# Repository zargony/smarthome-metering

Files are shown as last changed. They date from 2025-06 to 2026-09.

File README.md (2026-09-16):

# Smart Home Energy Metering

A device for capturing energy consumption at home by reading energy meters.

This device, built around an ESP32-C3, collects data from electricity, gas, and water meters and provides it to smart home systems like [Home Assistant] for automation and long-term analysis. Housed in a DIN rail enclosure, it fits seamlessly into a standard European meter cabinet.

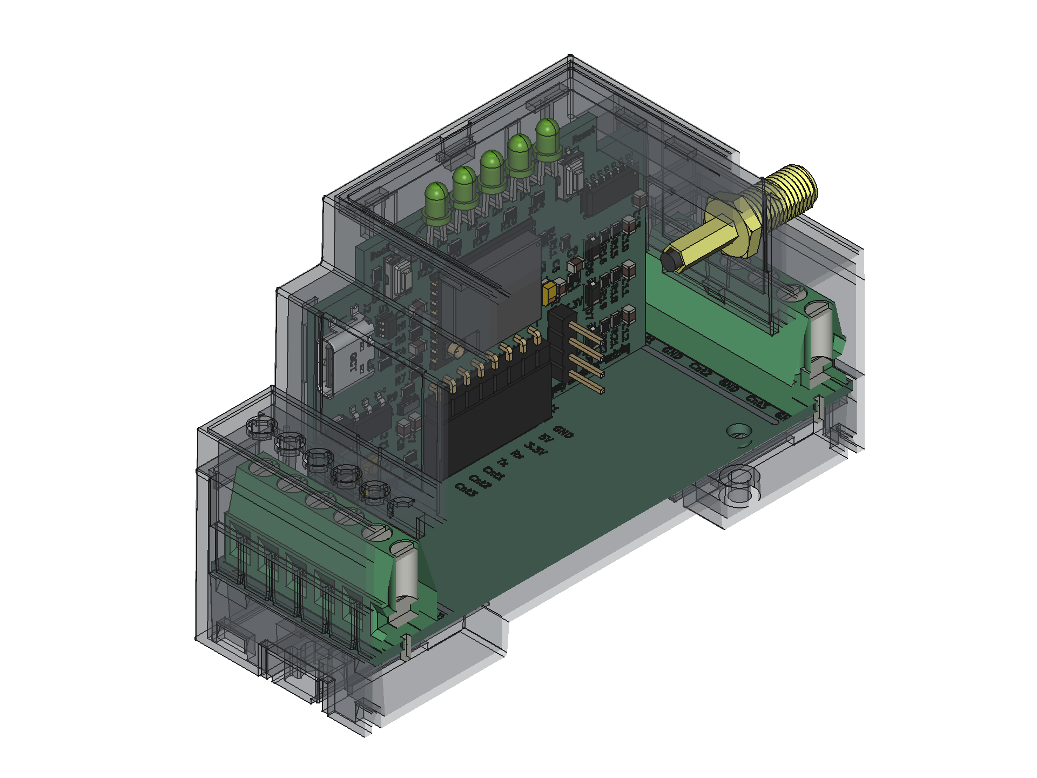
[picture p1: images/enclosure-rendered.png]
Rendering of PCB in enclosure
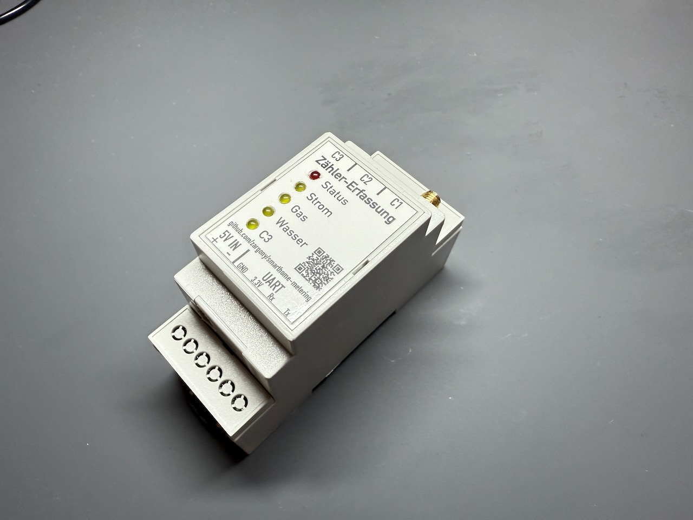
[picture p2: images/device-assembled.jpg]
Fully assembled device
 

## Hardware

The standard [DIN rail enclosure] can be mounted onto a DIN rail and shows status and activity LEDs when installed in a meter cabinet. [Power supply] and sensor connections are exposed via screw terminals. An external antenna can be connected to the SMA socket and is best mounted outside the cabinet for good Wifi connection. A USB-C socket exposes the ESP32-C3 Serial/JTAG port for easy programming/debugging (e.g. if OTA failed).

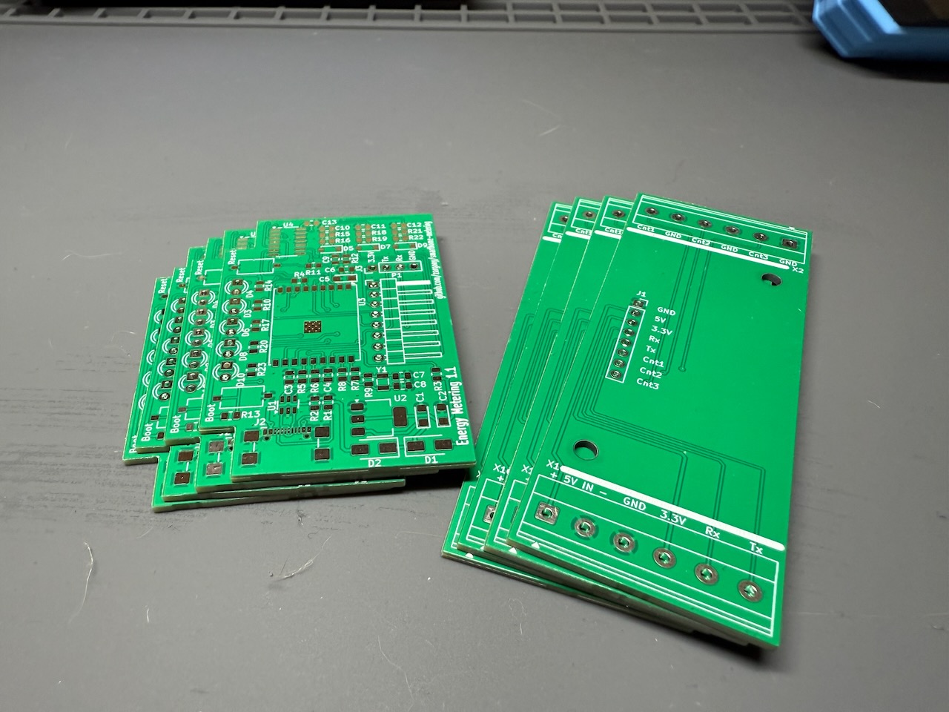
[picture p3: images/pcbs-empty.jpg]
Empty PCBs
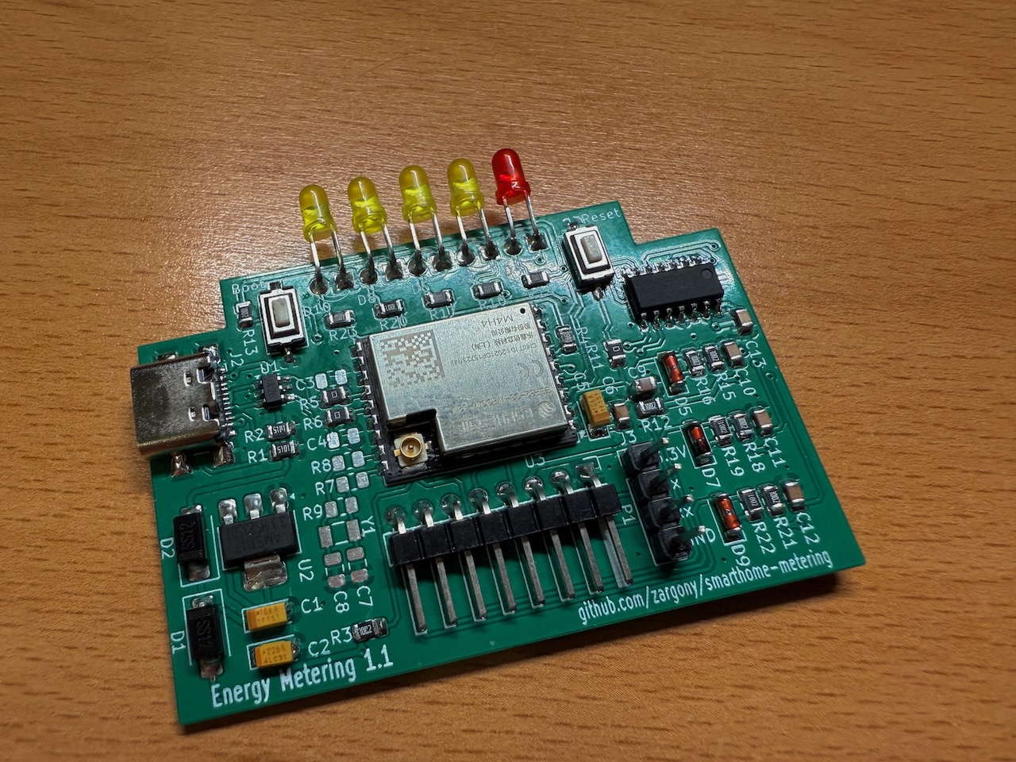
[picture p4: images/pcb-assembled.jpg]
Assembled main PCB
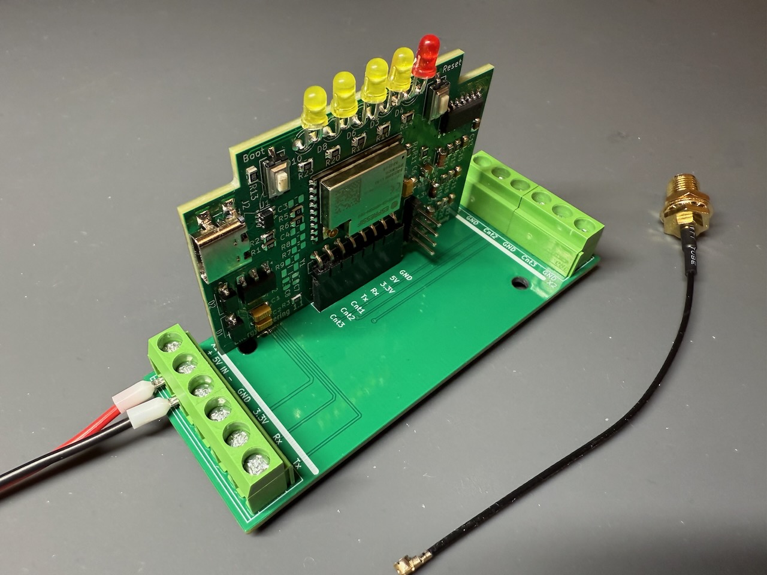
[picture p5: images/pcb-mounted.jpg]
Main PCB mounted onto base PCB
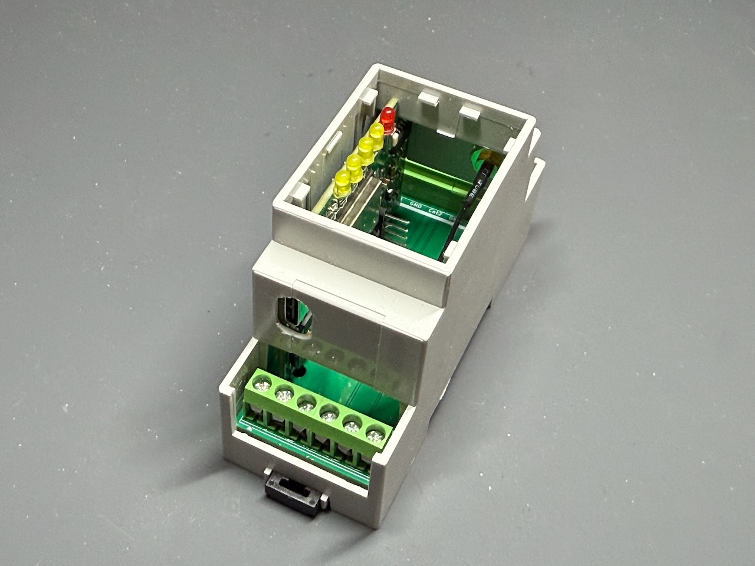
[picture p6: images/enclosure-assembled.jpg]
Enclosure and PCB assembled
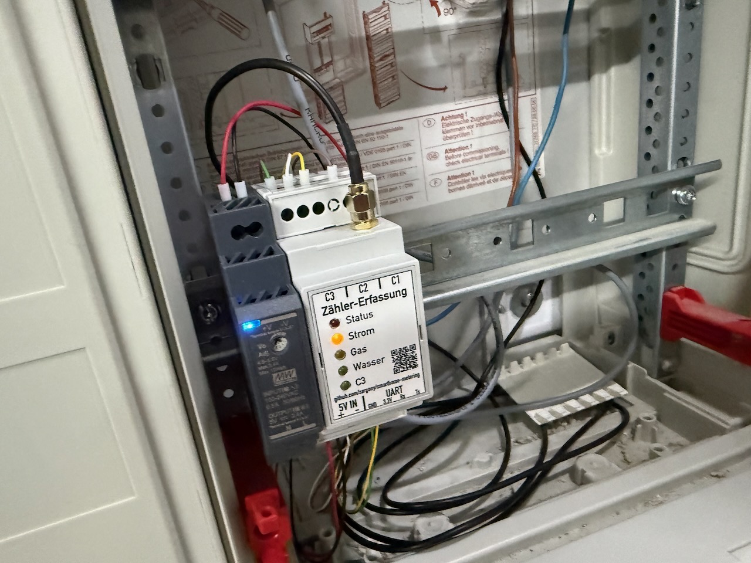
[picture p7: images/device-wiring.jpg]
Wiring of device in meter cabinet
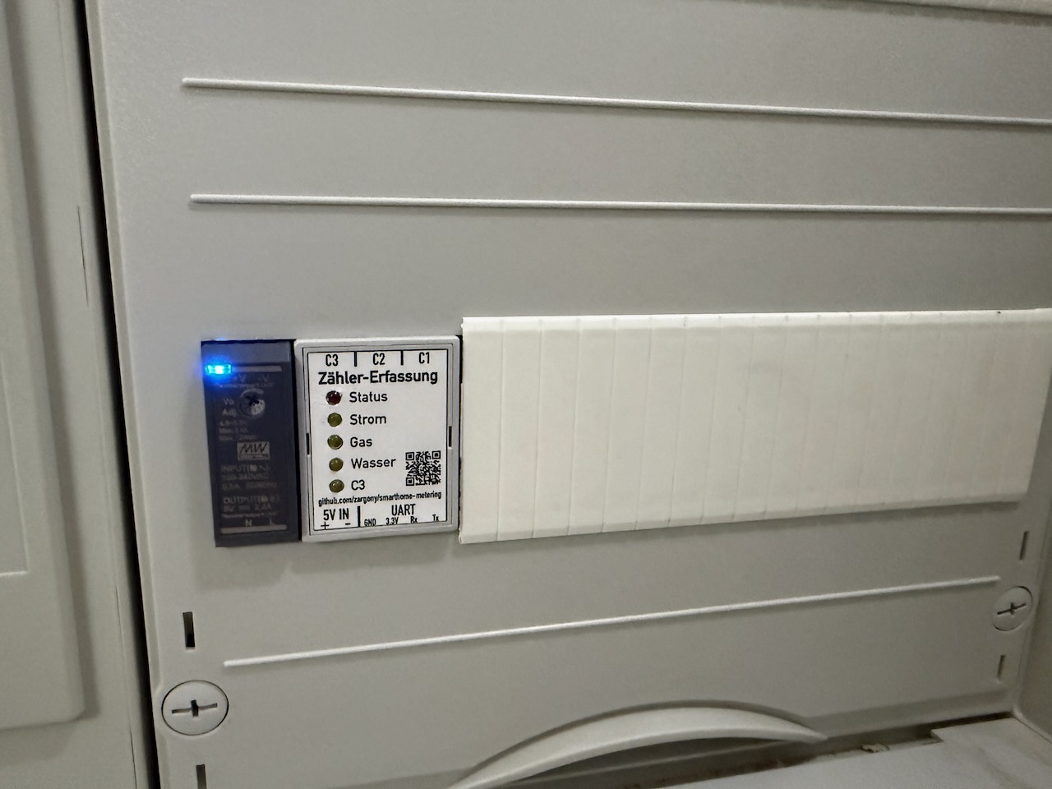
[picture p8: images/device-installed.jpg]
Device installed in meter cabinet
     

### Sensor connections

This device provides a 3.3V bidirectional UART for reading a serial data stream, e.g. an electric meter's infrared interface. Additionally 3 debounced impulse contacts can be used to capture simple count impulses, e.g. from reed contacts on water and gas meters (or electric meters without IR interface but impulse LEDs).

| GPIO  | Direction | Usage |
|---|---|---|
| GPIO3 | Input, Pull-Up, Debounced | Contact 1 (gas meter) |
| GPIO4 | Input, Pull-Up, Debounced | Contact 2 (water meter) |
| GPIO5 | Input, Pull-Up, Debounced | Contact 3 |
| GPIO6 | Input | UART Rx (electrical meter) |
| GPIO7 | Output | UART Tx |
| GPIO8 | Output | Status LED (active low) |
| GPIO9 | Input, Pull-Up | Boot button |

## Firmware

There's a variety of ESP32 firmwares available that can be used. Most popular are [ESPHome] and [Tasmota]. With proper configuration, it captures energy meters readings and can submit readings to [Home Assistant] or an MQTT broker where they can be picked up by various tools like [Node-RED] or [Telegraf].

See [`metering.yaml`](esphome/metering.yaml) for an example ESPHome configuration of this device which is auto-discovered with all metrics in Home Assistant.

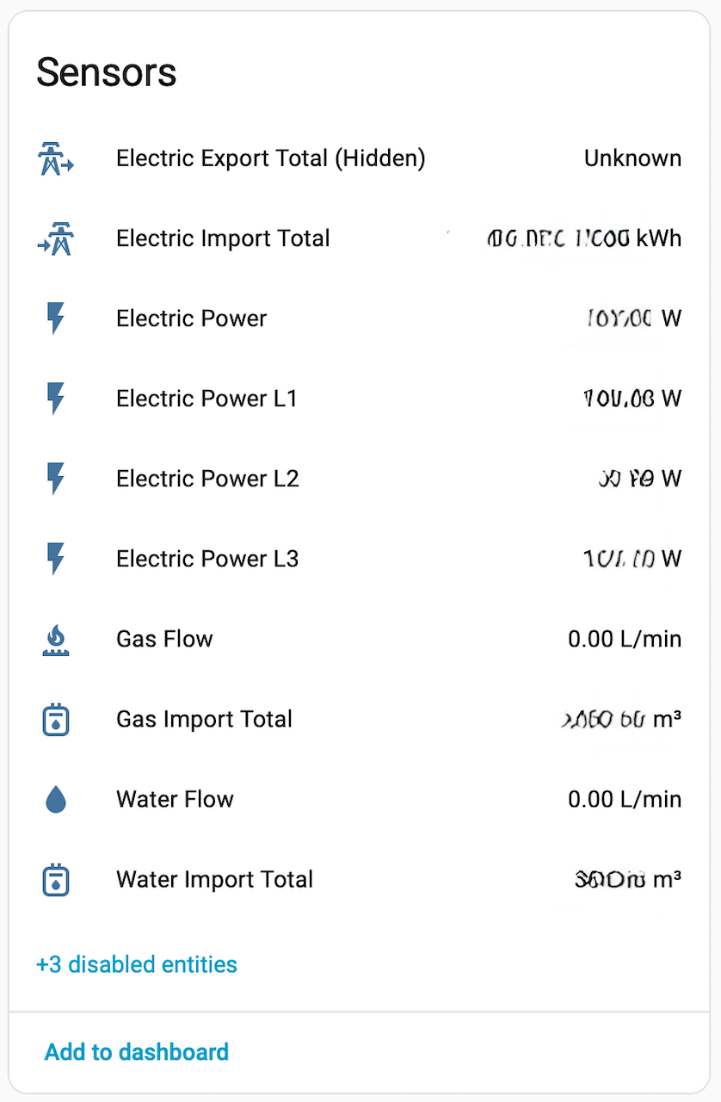
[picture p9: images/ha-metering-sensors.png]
Home Assistant showing energy metering sensors
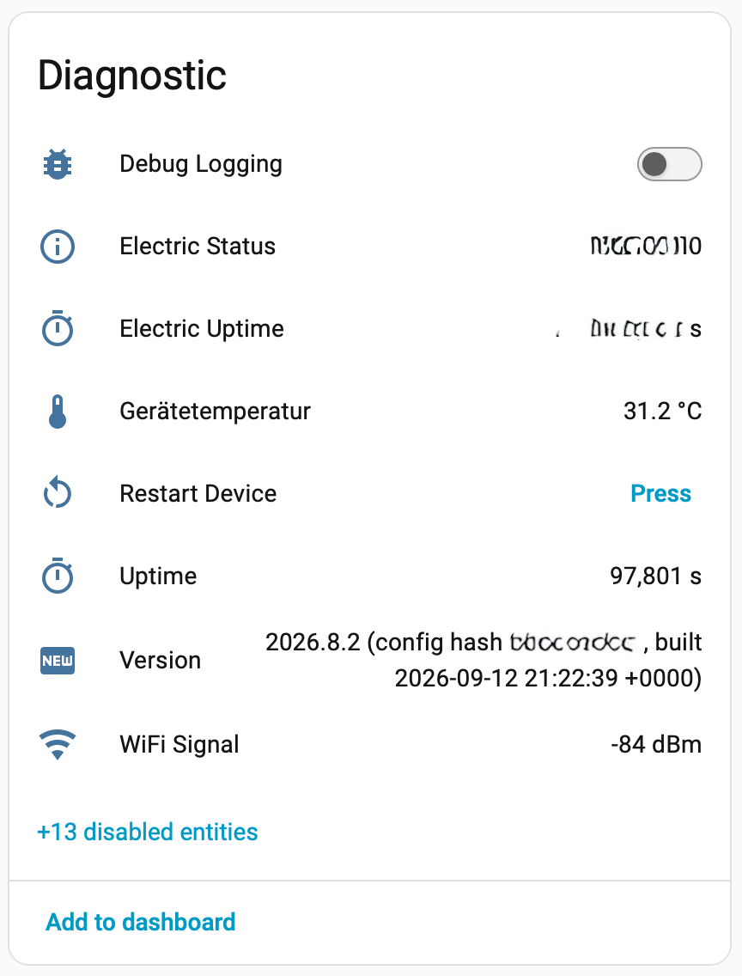
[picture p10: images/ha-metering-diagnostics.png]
Home Assistant showing device diagnostics
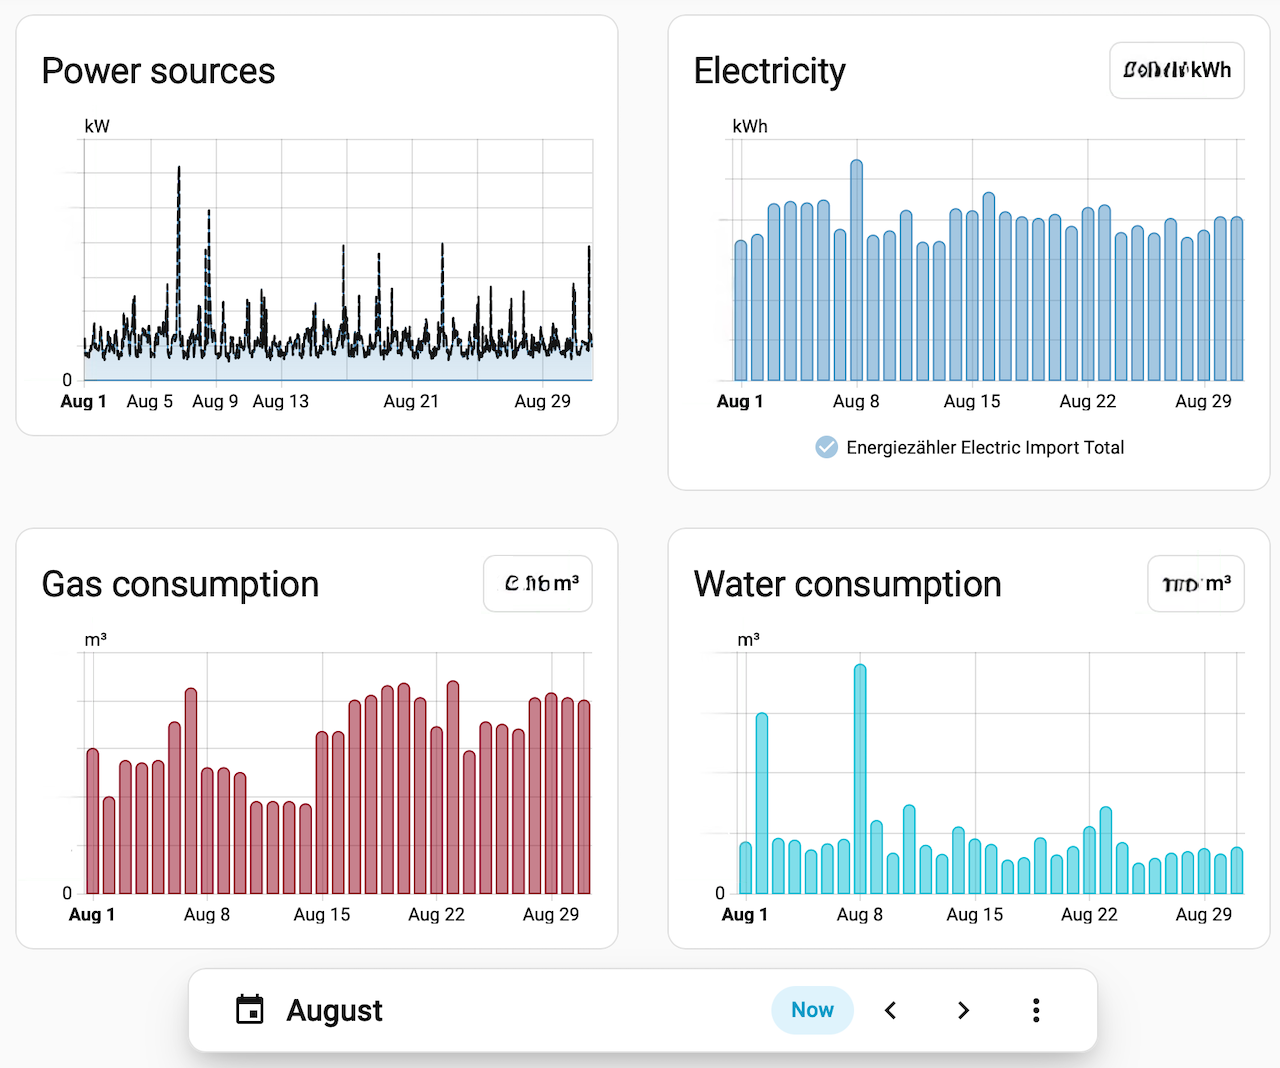
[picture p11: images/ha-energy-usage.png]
Home Assistant showing energy usage graphs
  

## My Setup (Example)

I use this device with sensors described below. It's tailored to my specific environment and some links reference German websites, as they relate to the energy meters installed in my home. However, you may still find parts of it useful for your own setup.

### Electrical

The [eBZ DD3] electrical meter has an infrared UART interface that continuously provides information about voltage, current, power and total consumption. Several [DIY IR sensors] (and [schematics][DIY IR sensor schmatic]) are available online, e.g. I got a Hichi IR (the simple TTL variant, no Wifi or USB). It works fine with 3.3V and is connected directly to this device. It continuously receives metering information in [OBIS D0] format (D0 is ASCII based, [unlike SML][OBIS is not SML]).

### Gas

A [Honeywell IN-Z61] impulse sensor is attached to my [GMT BK-G4] gas meter. One impulse is sent every 0.01 m³ (10 liters). Impulses are counted and summed up in software.

### Water

The water meter is similar to a [Sensus 420] water meter and allows to attach a [Sensus HRI] sensor. [Several variants][Sensus HRI datasheet] exist. HRI-A is a simple pulse emitter while HRI-B has an additional M-Bus data interface. While HRI-A would be sufficient, they don't seem to be available anymore nowadays. The pulse emitter is a trivial interface, similar to the gas meter. One impulse is sent every 0.001 m³ (1 liter). Impulses are counted and summed up in software.

## Contribution

Feel free to get in touch and discuss ideas, improvements or your experiences with it.

## License

Hardware licensed under the [CERN Open Hardware License (Strongly Reciprocal)][OHL]. Software licensed under the [European Union Public License (EUPL)][EUPL]. Unless you explicitly state otherwise, any contribution intentionally submitted for inclusion in the work by you, shall be licensed as above, without any additional terms or conditions.

## History

An early prototype was built using a NodeMCU V2 dev kit (ESP8266) on perfboard and used to dangle loosely next to the meter cabinet for way too long.

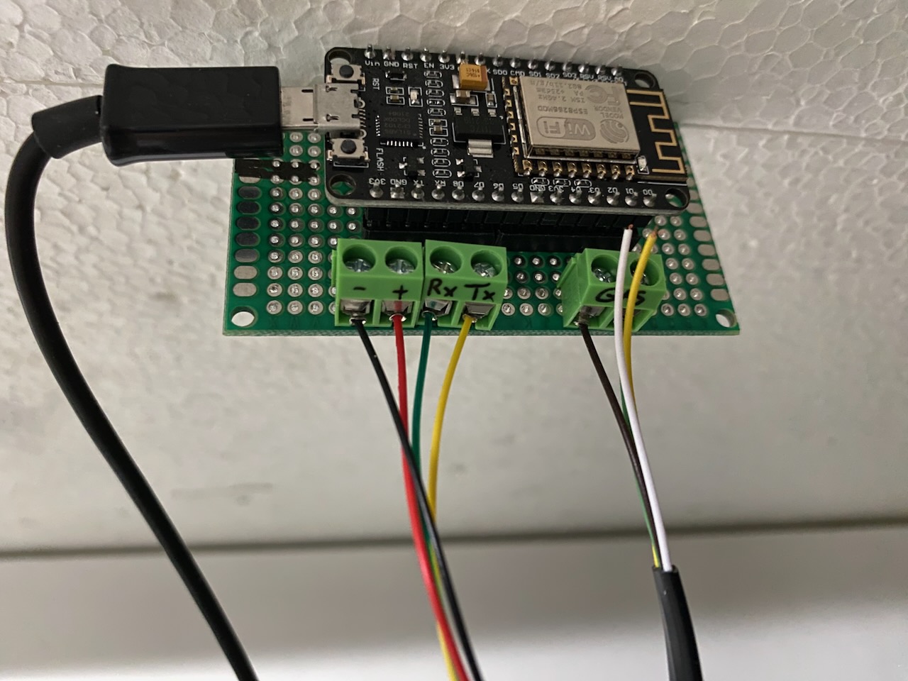
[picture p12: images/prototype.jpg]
Prototype on perfboard


<!-- Hardware links -->
[DIN rail enclosure]: https://www.camdenboss.com/camden-boss/cnmb2kit-din-rail-module-box-kit%2c-industrial-enclosure%2c-polycarbonate-enclosure/c-23/p-18578
[Power supply]: https://www.meanwell.com/webapp/product/search.aspx?prod=HDR-15

<!-- Electrical meter links -->
[eBZ DD3]: https://www.ebzgmbh.de/produkte/dd3
[DIY IR sensors]: https://www.heise.de/tests/Ausprobiert-Guenstiger-IR-Lesekopf-fuer-Smart-Meter-mit-Tastmota-Firmware-7065559.html
[DIY IR sensor schmatic]: https://wiki.volkszaehler.org/hardware/controllers/ir-schreib-lesekopf
[OBIS D0]: https://community.simon42.com/t/obis-d0-integration-und-ein-ebz-dd3-wechsel-von-tasmota-auf-esphome/20598
[OBIS is not SML]: https://community.simon42.com/t/ebz-dd3-esplesekopf-und-fehlende-daten/9765/4

<!-- Gas meter links -->
[Honeywell IN-Z61]: https://process.honeywell.com/us/en/site/elster-instromet-de/produkte/gasmessung/balgengaszahler/in-z61
[GMT BK-G4]: https://www.gmt.de/gasmessung/haushalt/bk-g-4

<!-- Water meter links -->
[Sensus 420]: https://www.xylem.com/de-de/products--services/metrology-equipment-for-utilities/meters/420-water-meter/
[Sensus HRI]: https://www.xylem.com/de-de/products--services/telemetry-communications--data-transfer/hand-held--reading-devices/hri-sensor/
[Sensus HRI datasheet]: https://www.xylem.com/siteassets/brand/sensus/resources/data-sheets/hri-sensor-data-sheet.pdf

<!-- Firmware links -->
[ESPHome]: https://esphome.io/
[Tasmota]: https://tasmota.github.io/

<!-- Software links -->
[Home Assistant]: https://www.home-assistant.io/
[Node-RED]: https://nodered.org/
[Telegraf]: https://www.influxdata.com/time-series-platform/telegraf/
[Grafana]: https://grafana.com/

<!-- License links -->
[OHL]: https://cern-ohl.web.cern.ch/home
[EUPL]: https://interoperable-europe.ec.europa.eu/collection/eupl/eupl-text-eupl-12

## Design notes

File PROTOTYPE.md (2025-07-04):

# Metering with NodeMCU (obsolete)

**Hardware and configuration described here was previously used as a prototype and is now obsolete.**

## Hardware

- NodeMCU Amica v2 Board (ESP 8266)
- Electric meter: Hichi IR TTL v1.1
- Gas meter: Honeywell IN-Z61 impulse counter

## NodeMCU Wiring

GPIO0: D3 / Boot0 / Flash Button
GPIO1: D10 / Tx0 (USB)
GPIO2: D4 / Tx1 / ESP LED
GPIO3: D9 / Rx0 (USB)
GPIO4: D2
GPIO5: D1
GPIO12: D6
GPIO13: D7 / Rx2 / Electric meter Rx
GPIO14: D5 / Gas meter impulse
GPIO15: D8 / Tx2 / Electric meter Tx
GPIO16: D0 / Board LED

## Firmware Install

Firmware: [Tasmota](https://tasmota.github.io/) ([GitHub](https://github.com/arendst/tasmota), [Webinstaller](https://tasmota.github.io/install/), [Download](https://ota.tasmota.com/tasmota/release/))

**Note: Use `tasmota-scripting.bin` firmware which has scripting and smart home features enabled**

One-time hardware configuration and setup (via serial port or Wifi AP mode):

```text
Backlog Template {"NAME":"NodeMCU","GPIO":[1,3200,576,3232,1,1,1,1,1,1,1,1,320,1],"FLAG":0,"BASE":18}; Ssid1 xxxxxxxxxx; Password1 xxxxxxxxxx; OtaUrl http://ota.tasmota.com/tasmota/release/tasmota-minimal.bin.gz; Timezone 0; MqttHost mqtt.home.zargony.com
```

## Configuration

Console Script (in Tasmota UI select `Consoles` -> `Edit Script`. Make sure `Script enable` is enabled!):

```text
>D
>B
SerialConfig 7E1
TelePeriod 10
=>sensor53 r
>M 2
; +<M>,<rxGPIO>,<type>,<flag>,<parameter>,<jsonPrefix>{,<txGPIO>,<txPeriod>,<cmdTelegram>}
+1,13,o,0,9600,Electr,15
+2,14,c,1,100,Gas
; <M>,<decoder>@<scale><offs>,<label>,<UoM>,<var>,<precision>
1,1-0:1.8.0*255(@0.001,Consumption,Wh,consumption_total,5)
;1,1-0:1.8.1*255(@0.001,Consumption T1,Wh,consumption_t1,5)
;1,1-0:1.8.2*255(@0.001,Consumption T2,Wh,consumption_t2,5)
;1,1-0:2.8.0*255(@0.001,Export,Wh,export_total,5)
;1,1-0:2.8.1*255(@0.001,Export T1,Wh,export_t1,5)
;1,1-0:2.8.2*255(@0.001,Export T2,Wh,export_t2,5)
1,1-0:16.7.0*255(@1,Power,W,power_total,18)
1,1-0:36.7.0*255(@1,Power L1,W,power_l1,18)
1,1-0:56.7.0*255(@1,Power L2,W,power_l2,18)
1,1-0:76.7.0*255(@1,Power L3,W,power_l3,18)
;1,1-0:32.7.0*255(@1,Voltage L1,V,voltage_l1,1)
;1,1-0:52.7.0*255(@1,Voltage L2,V,voltage_l2,1)
;1,1-0:72.7.0*255(@1,Voltage L3,V,voltage_l3,1)
1,1-0:96.5.0*255(@#),Status,,status,0
;1,1-0:0.0.0*255(@#),Owner Identification,,owner_id,0
;1,1-0:96.1.0*255(@#),Device Identification,,device_id,0
;1,0-0:96.8.0*255(@#),Time of Operation,,time,0
2,1-0:1.8.0*255(@100,Consumption,m³,consumption_total,2)
#
```

<!-- Example serial dump:
14:06:30.096 : /EBZxxxxxxxxxxx_xxx
14:06:30.098 : 1-0:0.0.0*255(1EBZxxxxxxxxxx)
14:06:30.146 : 1-0:96.1.0*255(1EBZxxxxxxxxxx)
14:06:30.196 : 1-0:1.8.0*255(001234.12345678*kWh)
14:06:30.198 : 1-0:16.7.0*255(000370.35*W)
14:06:30.246 : 1-0:36.7.0*255(000123.45*W)
14:06:30.248 : 1-0:56.7.0*255(000123.45*W)
14:06:30.296 : 1-0:76.7.0*255(000123.45*W)
14:06:30.346 : 1-0:96.5.0*255(00112233)
14:06:30.349 : 0-0:96.8.0*255(00112233)
14:06:30.350 : !
-->

## Maintenance

### Electric Metering (meter 1)

- Disable parsing SML and dump to console instead: `sensor53 d1`
- Turn off dumps and resume normal operation: `sensor53 d0`

### Gas Metering (Meter 2)

- Set/adjust counter: `sensor53 c1 12345` (sets gas meter to 123.45 m³)

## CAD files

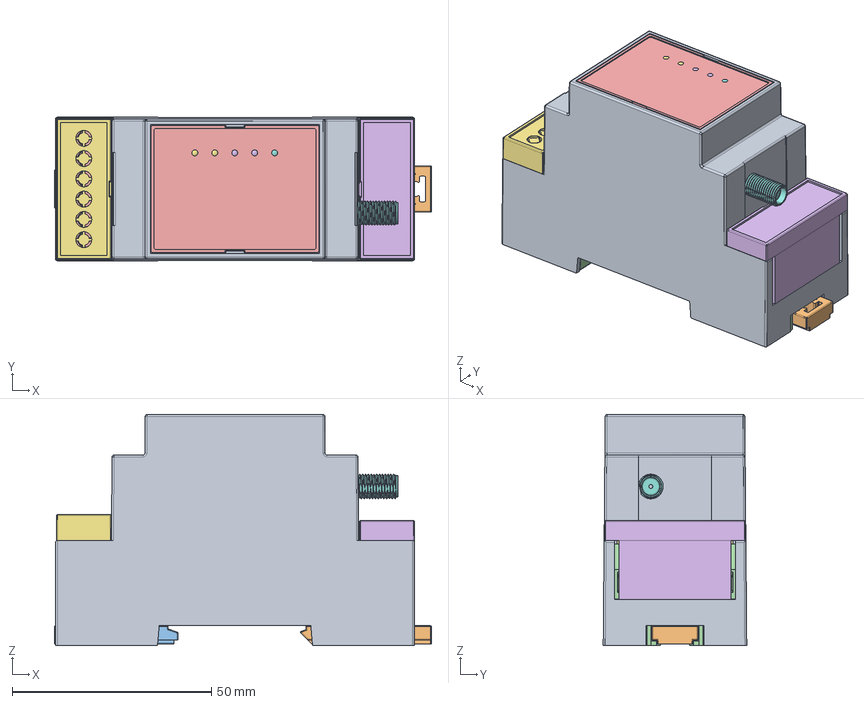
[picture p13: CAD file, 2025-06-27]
enclosure.FCStd
94.5 x 36.0 x 58.0 mm
CNMB-2-2-Top
CNMB-CB
CNMB-CW
CNMB-2-Base
CNMB-2-P
CNMB-2-TGS
CNMB-2-TG508P
SMA Jack
SOT-224
R_0805_2012Metric111
PinHeader_1x08_P2.54mm_Horizontal
R_0805_2012Metric112
R_0805_2012Metric113
SW_Tactile_SPST_NO_Straight_CK_PTS636Sx25SMTRLFS
R_0805_2012Metric114
R_0805_2012Metric115
SOIC-14_3.9x8.7mm_P1.27mm001
SW_Tactile_SPST_NO_Straight_CK_PTS636Sx25SMTRLFS001
R_0805_2012Metric116
CP_EIA-3216-18_Kemet-A013
D_SOD-136
R_0805_2012Metric117
ESP32-C3-WROOM-02U
C_0805_2012Metric040
R_0805_2012Metric118
C_0805_2012Metric041
R_0805_2012Metric119
C_0805_2012Metric042
C_0805_2012Metric043
LED_D3.0mm_Horizontal_O3.81mm_Z2.0mm016
D_SOD-137
LED_D3.0mm_Horizontal_O3.81mm_Z2.0mm017
R_0805_2012Metric120
D_SMA008
R_0805_2012Metric121
C_0805_2012Metric044
R_0805_2012Metric122
R_0805_2012Metric123
SOT-23-007
PinHeader_1x04_P2.54mm_Vertical001
C_0805_2012Metric045
R_0805_2012Metric124
R_0805_2012Metric125
R_0805_2012Metric126
CP_EIA-3216-18_Kemet-A014
R_0805_2012Metric127
LED_D3.0mm_Horizontal_O3.81mm_Z2.0mm018
R_0805_2012Metric128
C_0805_2012Metric046
R_0805_2012Metric129
C_0805_2012Metric047
D_SOD-138
USB4110-GF-A_revB(1) MF
Crystal_SMD_3215-2Pin_3.2x1.5mm
CP_EIA-3216-18_Kemet-A015
R_0805_2012Metric130
R_0805_2012Metric131
C_0805_2012Metric048
R_0805_2012Metric132
D_SMA009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

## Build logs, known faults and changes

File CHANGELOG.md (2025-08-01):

# Smart Home Energy Metering Changelog

All notable changes to this project will be documented in this file.

The format is based on [Keep a Changelog](https://keepachangelog.com/en/1.1.0/).

## Unreleased

## 1.2 - 2025-08-01

- Re-routed contacts to fix order on terminal header
- Fixed UART LED polarity to not light up during idle Rx (high level)

## 1.1 - 2025-06-30

- Submitted for manufacturing (JLCPCB)
- Added more GND vias
- Adjusted board constrains to allow easier (cheaper) manufacturing

## 1.0 - 2025-06-27

- Posted for review on [r/PrintedCircuitBoard](https://www.reddit.com/r/PrintedCircuitBoard/comments/1llyu23/review_request_esp32c3_board_for_reading_energy/)
- 2-layer base and vertical PCB for CNMB-2-2 DIN rail enclosure
- 3.3V UART for reading electrical meter's IR interface
- 3 debounced digital inputs for reading gas and water reed contacts
- status/activity LEDs
- power supply via 5V DC IN
- external SMA antenna connector
- USB-C for updating/debugging/power (safe to use while connected to 5V DC)

## 0.1 - 2023-11-28

- NodeMCU ESP8266 prototype on perfboard

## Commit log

2023-11-28 Initial KiCad project
    [metering.kicad_pcb, metering.kicad_sch]
2023-11-28 Add NodeMCU module
    [metering.kicad_sch]
2023-11-28 Add schematics for electric and gas meter as built in 11/2022
    [metering.kicad_sch]
2023-11-28 Add NodeMCU footprint
    [metering.kicad_sch]
2023-11-30 Add reed debounce circuit
    [metering.kicad_sch]
2023-12-01 Add SeeedStudio XIAO symbols and footprint
2024-01-07 Reduce debounce capacitor to 100n
    [metering.kicad_sch]
2024-01-07 Add remark about required diode for external VIN
    [metering.kicad_sch]
2024-02-26 Update to KiCad 8.0
    [metering.kicad_pcb, metering.kicad_sch]
2024-02-27 Pin currently used NodeMCU symbol and footprint as well
2025-05-19 Update to KiCad 9.0
    [metering.kicad_pcb, metering.kicad_sch]
2025-05-26 Update power symbols, add power flags to satisfy ERC
    [metering.kicad_sch]
2025-05-28 Update Seeed Studio XIAO symbols and footprint
2025-05-28 Refactor NodeMCU footprint
2025-06-09 Create base PCBs for Camdenboss CNMB-2-2 DIN rail enclosure
    [metering.kicad_pcb]
2025-06-10 Recreate schematic with ESP32-C3-WROOM module and hardware debounce
    [debounce.kicad_sch, metering.kicad_sch]
2025-06-15 Adjust some footprints and PCB settings
    [debounce.kicad_sch, metering.kicad_pcb, metering.kicad_sch]
2025-06-16 Remove UART Tx LED
    [debounce.kicad_sch, metering.kicad_sch]
2025-06-16 Refactor screw terminals and power supply
    [metering.kicad_sch]
2025-06-18 Fix base plate separation and power flags
    [debounce.kicad_sch, metering.kicad_sch]
2025-06-18 Adjust PCB design rule constraints to JLCPCB capabilities
2025-06-18 Add comment about debounce time calculation
    [debounce.kicad_sch]
2025-06-18 Improve schematic style
    [debounce.kicad_sch, metering.kicad_sch]
2025-06-26 PCB layout
    [metering.kicad_pcb]
2025-06-27 Update debounce time calculation
    [debounce.kicad_sch, metering.kicad_pcb, metering.kicad_sch]
2025-06-27 Add 3d model of pcb in enclosure
    [enclosure.FCStd]
2025-06-30 Add image of rendered PCB in enclosure
2025-06-30 Update README with information about current environment
2025-06-30 Add image of prototype perfboard
2025-06-30 Change board constrains to allow easier (cheaper) manufacturing
    [metering.kicad_pcb]
2025-06-30 Add more GND vias
    [metering.kicad_pcb]
2025-06-30 Fix pcb manufacturing warnings
    [metering.kicad_pcb]
2025-06-30 Release 1.1
    [debounce.kicad_sch, metering.kicad_pcb, metering.kicad_sch]
2025-07-04 Add old prototype hardware information
2025-07-15 Prepare 1.2-dev
    [debounce.kicad_sch, metering.kicad_pcb, metering.kicad_sch]
2025-07-15 Fix contact labels order on silkscreen and front label
    [metering.kicad_pcb]
2025-07-15 Align power symbols
    [metering.kicad_sch]
2025-07-15 Fix UART LED polarity to not light up during idle Rx (high level)
    [debounce.kicad_sch, metering.kicad_pcb, metering.kicad_sch]
2025-08-01 Re-route contacts to fix order on terminal header
    [debounce.kicad_sch, metering.kicad_pcb, metering.kicad_sch]
2025-08-01 Release 1.2
    [debounce.kicad_sch, metering.kicad_pcb, metering.kicad_sch]
2025-08-11 Silence ESPHome warning about strapping pin usage
2025-08-24 Use ESPHome esp32.variant instead esp32.board configuration as recommended
2025-08-25 Decrease water flow pulse meter timeout
2025-08-25 Switch gas flow unit of measurement to l/min
2026-09-17 Update to KiCad 10
    [debounce.kicad_sch, metering.kicad_pcb, metering.kicad_sch]
2026-09-20 Clear PCB and prepare layout for CNMB-3-2
    [debounce.kicad_sch, metering.kicad_pcb, metering.kicad_sch]
2026-09-20 Rework power supply and screw terminal connections
    [debounce.kicad_sch, metering.kicad_sch]
2026-09-25 Rework digital inputs, add analog inputs and digital outputs
    [analog-in.kicad_sch, digital-in.kicad_sch, digital-out.kicad_sch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]
